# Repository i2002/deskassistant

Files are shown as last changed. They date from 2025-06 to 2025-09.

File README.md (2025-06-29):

# Deskassistant

## Introduction
Deskassistant is a compact device designed to help you increase your productivity. Placed on your desk, it keeps track of your priorities for the day and the time spent for each one. This project was presented as my graduation thesis for Computer Engineering Bachelor's Degree at Faculty of Mathematics and Computer Science, University of Bucharest.

## Repository structure
This repository contains the following:
- the software application written in QT
- PCB design for the connection board between Raspberry Pi Compute Module 5 and the rest of the peripherals (LCD display, touchscreen input, side buttons, brightness control, USB 2.0 interface)
- 3D design for the case backplate
- information about the OS-level configuration

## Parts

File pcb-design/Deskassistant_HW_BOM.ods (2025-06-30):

Reference | Description | Qty | Value | DNP | MPN | Manufacturer | SPN (Digikey) | URL | Exclude from BOM | Exclude from Board | Footprint | Footprint source | Datasheet
C1,C4,C26,C31,C37,C39,C45 | Generic capacitors | 7 | 10uF |  | GPC0805106 | - |  |  |  |  | Capacitor_SMD:C_0805_2012Metric |  | ~
C2 | Generic capacitors | 1 | 22uF |  | GPC0805226 | - |  |  |  |  | Capacitor_SMD:C_0805_2012Metric |  | ~
C3,C38 | Generic capacitors | 2 | 1uF |  | GPC0805105-25 | - |  |  |  |  | Capacitor_SMD:C_0805_2012Metric |  | ~
C5 | 470µF 25V Aluminum Electrolytic Capacitors Radial, Can - SMD 5000 Hrs @ 105°C | 1 | 470uF |  | 865060457009 | Wurth Elektronik | 732-8538-1-ND |  |  |  | Deskassistant_HW:CAPAE1030X1050L350X90N |  | ~
C6 | Generic capacitors | 1 | 2.7nF |  | GPC0805222 | - |  |  |  |  | Capacitor_SMD:C_0805_2012Metric |  | ~
C7 | Generic capacitors | 1 | 8.2nF |  | GPC0805682 | - |  |  |  |  | Capacitor_SMD:C_0805_2012Metric |  | ~
C8,C12,C18,C23 | Generic capacitors | 4 | 10uF |  | GPC1210106-25 | - |  |  |  |  | Capacitor_SMD:C_1210_3225Metric |  | ~
C9,C10,C11,C13,C14,C15,C16,C17,C19,C20,C21,C22,C24,C25,C46 | Generic capacitors | 15 | 0.1uF |  | GPC0805104 | - |  |  |  |  | Capacitor_SMD:C_0805_2012Metric |  | ~
C27,C30,C35 | Generic capacitors | 3 | 4.7uF |  | GPC0805475-16 | - |  |  |  |  | Capacitor_SMD:C_0805_2012Metric |  | ~
C28,C32,C34 | Generic capacitors | 3 | 220nF |  | GPC0805224 | - |  |  |  |  | Capacitor_SMD:C_0805_2012Metric |  | ~
C29,C40,C41,C42,C43,C44 | Generic capacitors | 5 | 100nF |  | GPC0805104 | - |  |  |  |  | Capacitor_SMD:C_0805_2012Metric |  | ~
C33 | Generic capacitors | 1 | 220nF |  | GPC0805224 | - |  |  |  |  | Capacitor_SMD:C_0805_2012Metric |  | ~
C36 | CAP CER 36PF 50V C0G/NP0 0805 | 1 | 36pF |  | C0805C360J5GACTU | Kemet | 399-C0805C360J5GACTUCT-ND |  |  |  | Capacitor_SMD:C_0805_2012Metric |  | ~
C47 | Tantalum Capacitors - Solid SMD 10V 150uF 10% | 1 | 150uF |  | TPSD157K010S0100 | AVX | 478-TPSD157K010S0100TR-ND |  |  |  | Capacitor_SMD:C_1210_3225Metric |  | ~
D1 | TVS DIODE 5VWM 9.2VC DO214AC | 1 | 5V |  | SMAJ5.0CA | Littlefuse | SMAJ5.0CALFCT-ND |  |  |  | Deskassistant_HW:DIONM510X266X229L115X145N |  | https://assets.nexperia.com/documents/data-sheet/PTVS10VZ1USK.pdf (https://www.murata.com/products/productdata/8796738650142/ENFA0003.pdf)
D2,D3,D4,D6,D7 | Diode Schottky 40V 1A Surface Mount SMA (DO-214AC) | 5 | SS14 |  | SS14 | ON Semiconductor | SS14DKR-ND |  |  |  | Diode_SMD:D_SMA |  | ~
D5 | Zener Diode 5.6 V 500 mW ±2% Surface Mount SOD-123 | 1 | 5.6V |  | MMSZ5232C-E3-08 | Vishay | MMSZ5232C-E3-08GICT-ND | https://www.digikey.com/en/products/detail/vishay-general-semiconductor-diodes-division/MMSZ5232C-E3-08/4832382 |  |  | Diode_SMD:D_SOD-123 |  | https://www.vishay.com/docs/86344/mmsz5225_to_mmsz5267.pdf
D8 | Zener Diode 9.1 V 500 mW ±2% Surface Mount SOD-123 | 1 | 9.1V |  | MMSZ5239C-E3-08 | Vishay | MMSZ5239C-E3-08GICT-ND | https://www.digikey.com/en/products/detail/vishay-general-semiconductor-diodes-division/MMSZ5239C-E3-08/4832424 |  |  | Diode_SMD:D_SOD-123 |  | https://www.vishay.com/docs/86344/mmsz5225_to_mmsz5267.pdf
FB1,FB2,FB3,FB4 | Ferrite Beads Multi-Layer 600Ohm 25% 100MHz 200mA 600mOhm DCR 0603 Paper T/R | 4 |  |  | BLM18RK601SN1D | Murata | 490-5227-1-ND | https://www.digikey.com/en/products/detail/murata-electronics/BLM18RK601SN1D/1948332 |  |  | Inductor_SMD:L_0603_1608Metric |  | https://www.murata.com/products/productdata/8796738650142/ENFA0003.pdf
J1 | USB-C (USB TYPE-C) USB 2.0 Receptacle Connector 24 (16+8 Dummy) Position | 1 |  |  | USB4145-03-0170-C | GCT | 2073-USB4145-03-0170-CCT-ND | https://www.digikey.com/en/products/detail/gct/USB4145-03-0170-C/16649098 |  |  | Deskassistant_HW:CONN_GCT_USB4145-03-0170-C |  | https://gct.co/files/specs/usb4145-spec.pdf
J2 | 6 Position FFC, FPC Connector Contacts, Bottom 0.020" (0.50mm) Surface Mount, Right Angle | 1 | Conn_01x06_Socket |  | 0527460671 | Molex | WM7977CT-ND | https://www.digikey.com/en/products/detail/molex/0527460671/2074148?s=N4IgTCBcDaIAwFYwHYAsA2O7kEYQF0BfIA |  |  | Deskassistant_HW:MOLEX_0527460671 |  | ~
J3 | 50 Position FPC Connector Contacts, Top 0.020" (0.50mm) Surface Mount, Right Angle | 1 | 62684-502100ALF |  | 62684-502100ALF | Amphenol | 609-1202-1-ND | https://www.digikey.com/en/products/detail/amphenol-cs-fci/62684-502100ALF/1001516 |  |  | Deskassistant_HW:CONN50_62684-502100ALF_FCI |  | https://www.waldom.com/upload/parts/datasheets/mf-fci/fci-62684-502100alf.pdf
J4 | USB-A (USB TYPE-A) USB 2.0 Receptacle Connector 4 Position Through Hole | 1 | USB_A |  | UE27AE54100 | Amphenol | UE27AE54100-ND | https://www.digikey.com/en/products/detail/amphenol-cs-commercial-products/UE27AE54100/1972254 |  |  | Deskassistant_HW:AMPHENOL_UE27AE54100 |  | ~
J5,J6 | 100 Position Connector Receptacle, Center Strip Contacts Surface Mount Gold | 2 | ComputeModule5 |  | 10164227-1001A1RLF | Amphenol | 609-10164227-1001A1RLFCT-ND | https://www.digikey.com/en/products/detail/amphenol-cs-fci/10164227-1001A1RLF/16908921 |  |  | Deskassistant_HW:CONN_AMPHENOL_10164227-1001A1RLF
L1 | 2.2 µH Shielded Drum Core, Wirewound Inductor 1.5 A 72mOhm Max Nonstandard | 1 | 2.2uH |  | NR3015T2R2M | Taiyo Yuden | 587-1648-1-ND | https://www.digikey.com/en/products/detail/taiyo-yuden/NR3015T2R2M/958029 |  |  | Deskassistant_HW:L_NR3015T2R2M |  | https://mm.digikey.com/Volume0/opasdata/d220001/medias/docus/610/NR3015T2R2M_SS.pdf
L2,L3 | 10 µH Shielded Drum Core, Wirewound Inductor 1.13 A 237mOhm Max Nonstandard | 2 | 10uH |  | VLCF5020T-100M1R1-1 | TDK | 445-3209-1-ND | https://www.digikey.com/en/products/detail/tdk-corporation/VLCF5020T-100M1R1-1/1132635 |  |  | Inductor_SMD:L_Sumida_CR75 |  | https://product.tdk.com/en/system/files
Q1 | Bipolar (BJT) Transistor NPN 40 V 600 mA 300MHz 300 mW Surface Mount SOT-23-3 | 1 | 1AM |  | BC847A,215 | Nexperia | 1727-4240-1-ND | https://www.digikey.com/en/products/detail/nexperia-usa-inc/BC847A-215/1232273 |  |  | Package_TO_SOT_SMD:SOT-23 |  | https://www.onsemi.com/pdf/datasheet/pzt3904-d.pdf (https://www.murata.com/products/productdata/8796738650142/ENFA0003.pdf)
R1 | Generic resistor | 1 | 2.2k |  | GPR08052K2 | - |  |  |  |  | Resistor_SMD:R_0805_2012Metric |  | ~
R2,R3,R4,R5,R6,R12,R13,R16,R17,R18,R19,R20,R31,R32,R33 | Generic resistor | 15 | 10k |  | GPR080510K | - |  |  |  |  | Resistor_SMD:R_0805_2012Metric |  | ~
R7 | Generic resistor | 1 | 470k |  | GPR0805470K | - |  |  |  |  | Resistor_SMD:R_0805_2012Metric |  | ~
R8 | Generic resistor | 1 | 178k |  | GPR0805180K | - |  |  |  |  | Resistor_SMD:R_0805_2012Metric |  | ~
R9 | Generic resistor | 1 | 681 |  | GPR0805680R | - |  |  |  |  | Resistor_SMD:R_0805_2012Metric |  | ~
R10 | Generic resistor | 1 | 47k |  | GPR080547K | - |  |  |  |  | Resistor_SMD:R_0805_2012Metric |  | ~
R11 | Generic resistor | 1 | 17.4k |  | GPR080518K | - |  |  |  |  | Resistor_SMD:R_0805_2012Metric |  | ~
R14,R15,R21,R22,R23,R26 | Generic resistor | 6 | 0 | DNP | GPR080510K |  |  |  |  |  | Resistor_SMD:R_0805_2012Metric |  | ~
R24 | Generic resistor | 1 | 22 |  | GPR080522R | - |  |  |  |  | Resistor_SMD:R_0805_2012Metric |  | ~
R25 | Generic resistor | 1 | 1k |  | GPR08051K | - |  |  |  |  | Resistor_SMD:R_0805_2012Metric |  | ~
R27 | Generic resistor | 1 | 1.27 |  | GPR08051R2 | - |  |  |  |  | Resistor_SMD:R_0805_2012Metric |  | ~
R28 | Generic resistor | 1 | 15k |  | GPR080515K | - |  |  |  |  | Resistor_SMD:R_0805_2012Metric |  | ~
R29 | Generic resistor | 1 | 6.8k |  | GPR08056K8 | - |  |  |  |  | Resistor_SMD:R_0805_2012Metric |  | ~
R30 | Generic resistor | 1 | 120k |  | GPR0805120K | - |  |  |  |  | Resistor_SMD:R_0805_2012Metric |  | ~
RN1,RN2,RN3,RN4,RN5,RN6,RN7 | 33 Ohm ±1% 31mW Power Per Element Isolated 4 Resistor Network/Array ±200ppm/°C 0502 (1406 Metric) Convex, Long Side Terminals | 7 | 33 |  | CAY16-33R0F4LF | Bourns | CAY16-33R0F4LFCT-ND | https://www.digikey.ro/en/products/detail/bourns-inc/CAY16-33R0F4LF/2566572 |  |  | Resistor_SMD:R_Array_Convex_4x0603 |  | https://www.bourns.com/docs/Product-Datasheets/CATCAY.pdf
RV1 |  | 1 | ~ |  | TS53YL103MR10 | Vishay Sfernice | TS53YL-10KCT-ND | https://www.digikey.com/en/products/detail/vishay-sfernice/TS53YL103MR10/1587849 |  |  | Potentiometer_SMD:Potentiometer_Bourns_3214J_Horizontal |  | https://www.vishay.com/docs/51008/ts53.pdf
SW1,SW2,SW3,SW4,SW5 | Tactile Switch SPST-NO Side Actuated Surface Mount, Right Angle | 5 | SW_Push |  | TL3330AF260QG | E-Switch | EG4389CT-ND | https://www.digikey.com/en/products/detail/e-switch/TL3330AF260QG/1426836 |  |  | Deskassistant_HW:SW_ESWITCH_TL3330AF260QG |  | ~
U1 | Buck Switching Regulator IC Positive Fixed 3.3V 1 Output 1A 8-WFDFN Exposed Pad | 1 |  |  | TPS62162DSGR | Texas Instruments | 296-43671-1-ND | https://www.digikey.com/en/products/detail/texas-instruments/TPS62162DSGR/2833447 |  |  | Package_SON:WSON-8-1EP_2x2mm_P0.5mm_EP0.9x1.6mm_ThermalVias | https://www.digikey.com/en/products/detail/texas-instruments/TPS62162DSGR/2833447 | http://www.ti.com/lit/ds/symlink/tps62160.pdf (https://www.murata.com/products/productdata/8796738650142/ENFA0003.pdf)
U2 | Electronic Fuse Regulator 5.5A 10-VQFN-HR (2x2) | 1 |  |  | TPS259472ARPWR | Texas Instruments | 296-TPS259472ARPWRCT-ND | https://www.digikey.com/en/products/detail/texas-instruments/TPS259472ARPWR/14124020 |  |  | Deskassistant_HW:RPW0010A-MFG |  | https://www.ti.com/general/docs/suppproductinfo.tsp?distId=10
U3 | 0/3 Receiver PanelBus™ 100-HTQFP (14x14) | 1 |  |  | TFP401APZPR | Texas Instruments | 296-53174-1-ND | https://www.digikey.com/en/products/detail/texas-instruments/TFP401APZPR/9861440 |  |  | Deskassistant_HW:PZP100_5P2X5P2 |  | https://www.ti.com/general/docs/suppproductinfo.tsp?distId=10
U4 | LED Driver IC 1 Output DC DC Regulator Step-Up (Boost) PWM Dimming 1.2A (Switch) SOT-23-6 | 1 |  |  | TPS61165DBVR | Texas Instruments | 296-27597-1-ND | https://www.digikey.com/en/products/detail/texas-instruments/TPS61165DBVR/2340764 |  |  | Package_TO_SOT_SMD:SOT-23-6 |  | https://www.ti.com/lit/ds/symlink/tps61165.pdf (https://www.murata.com/products/productdata/8796738650142/ENFA0003.pdf)
U5 | LED Driver IC 1 Output DC DC Regulator Step-Up (Boost) PWM Dimming 350mA (Switch) SOT-23-5 | 1 |  |  | TPS61040DBVR | Texas Instruments | 296-12685-1-ND | https://www.digikey.com/en/products/detail/texas-instruments/TPS61040DBVR/454263 |  |  | Package_TO_SOT_SMD:SOT-23-5 |  | http://www.ti.com/lit/ds/symlink/tps61040.pdf (https://www.murata.com/products/productdata/8796738650142/ENFA0003.pdf)
U6 | IC PWR SWITCH N-CHAN 1:1 SOT23-5 | 1 |  |  | TPS2041CDBVT | Texas Instruments | 296-35520-1-ND | https://www.digikey.com/en/products/detail/texas-instruments/TPS2041CDBVT/3778698 |  |  | Package_TO_SOT_SMD:SOT-23-5 |  | https://www.ti.com/lit/ds/symlink/tps2041c.pdf (https://www.murata.com/products/productdata/8796738650142/ENFA0003.pdf)

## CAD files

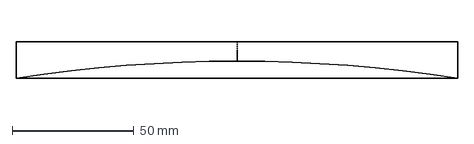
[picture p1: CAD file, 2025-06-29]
case-design/sketch_ecran_sides.dxf
181.0 x 15.0 mm

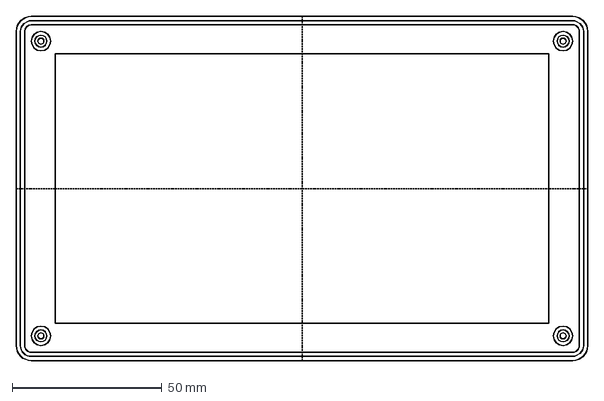
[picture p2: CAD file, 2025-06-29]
case-design/sketch_backplate_base.dxf
191.0 x 115.0 mm

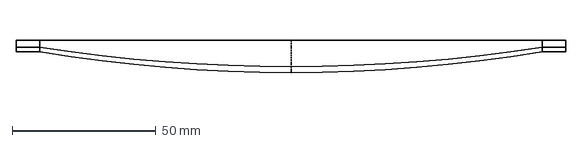
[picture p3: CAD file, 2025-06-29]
case-design/sketch_backplate_side.dxf
191.0 x 13.6 mm

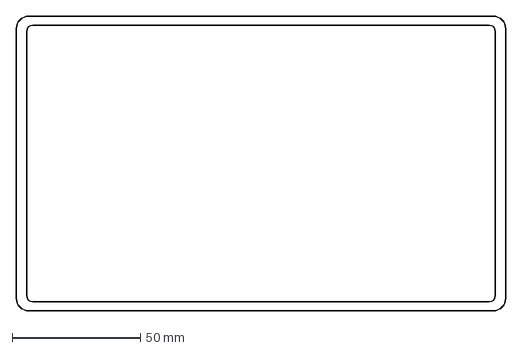
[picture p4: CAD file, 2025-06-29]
case-design/sketch_ecran_base.dxf
191.0 x 115.0 mm

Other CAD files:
case-design/Case - v1 v3.f3d

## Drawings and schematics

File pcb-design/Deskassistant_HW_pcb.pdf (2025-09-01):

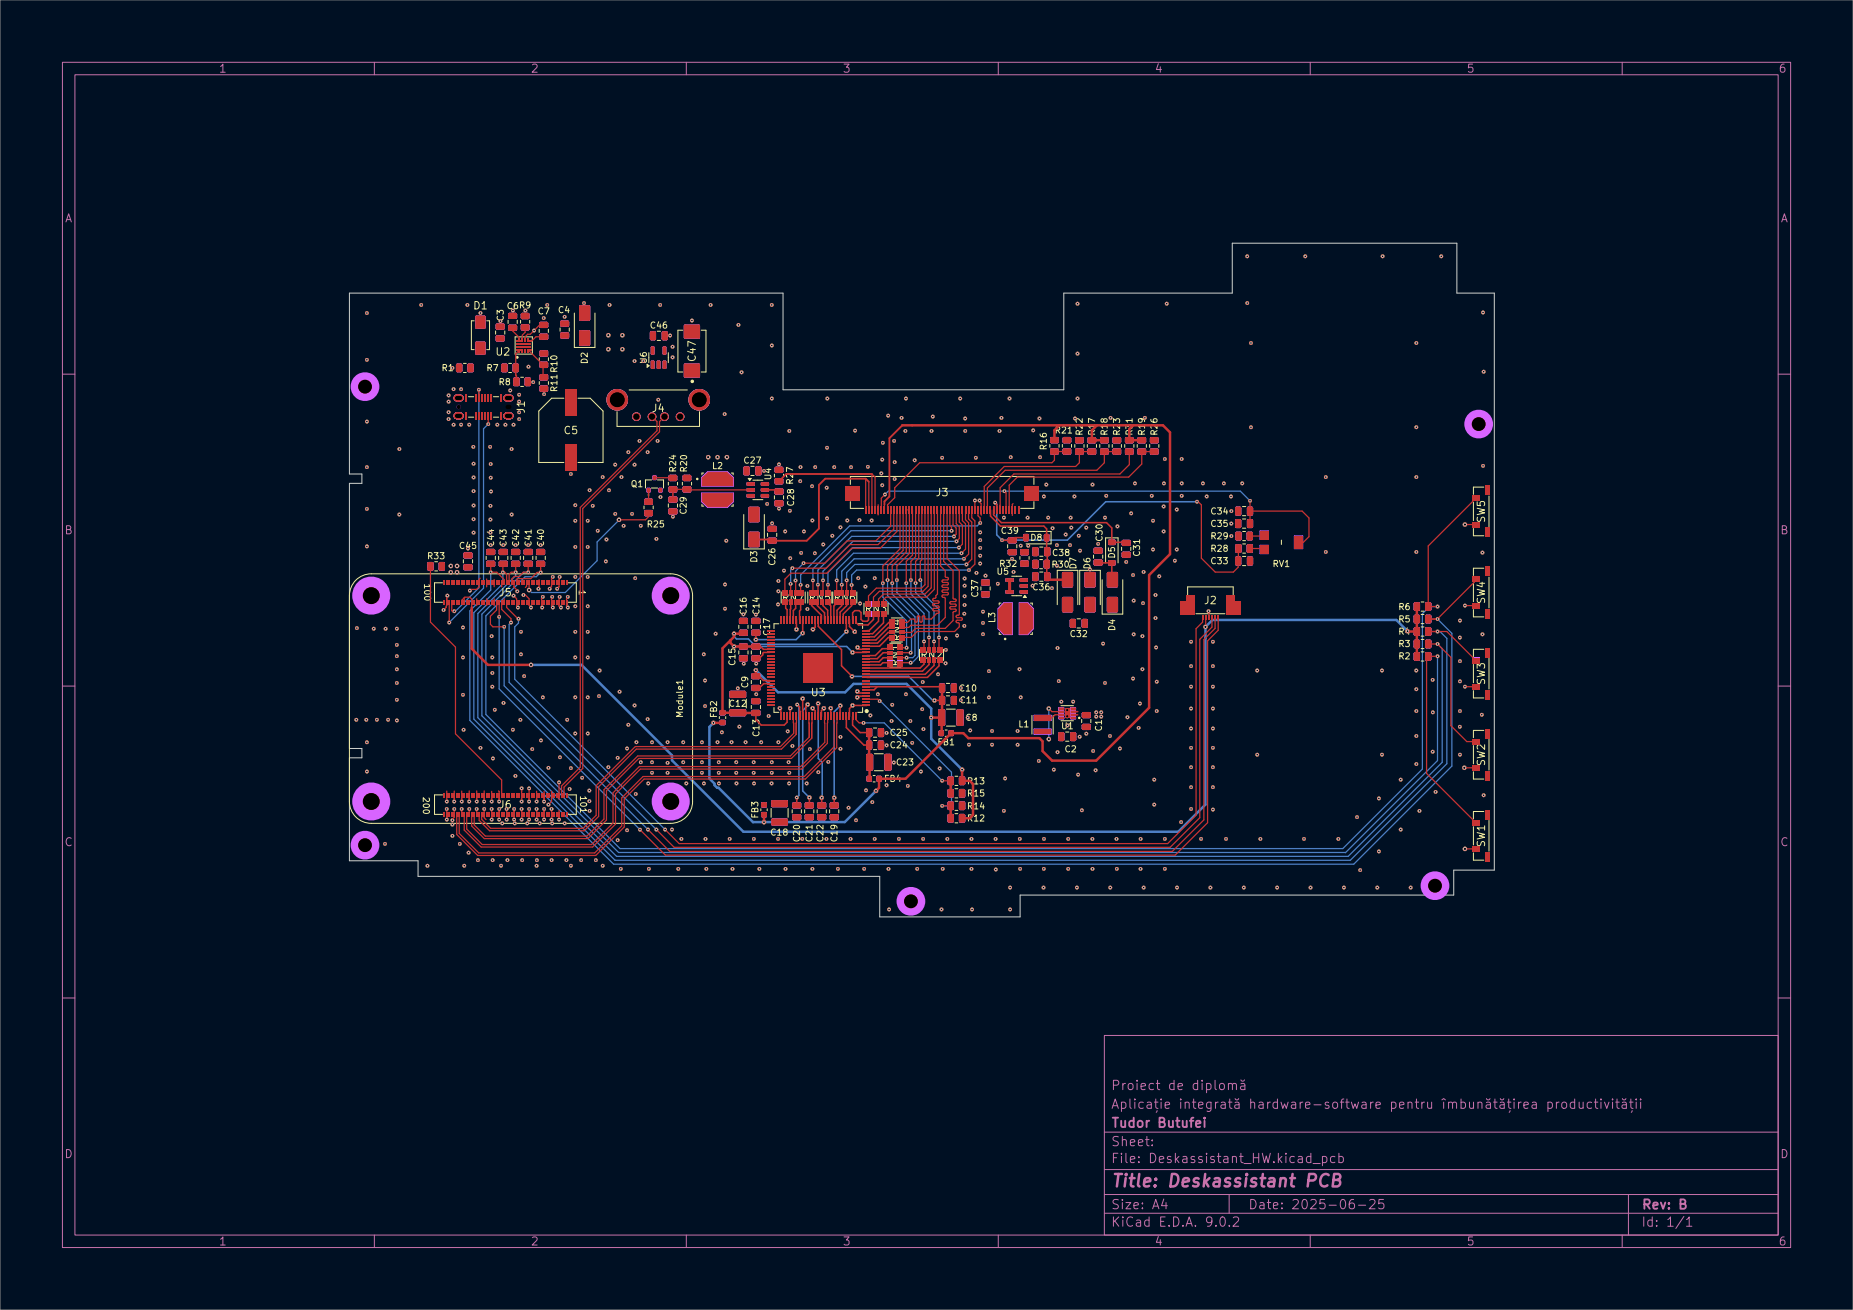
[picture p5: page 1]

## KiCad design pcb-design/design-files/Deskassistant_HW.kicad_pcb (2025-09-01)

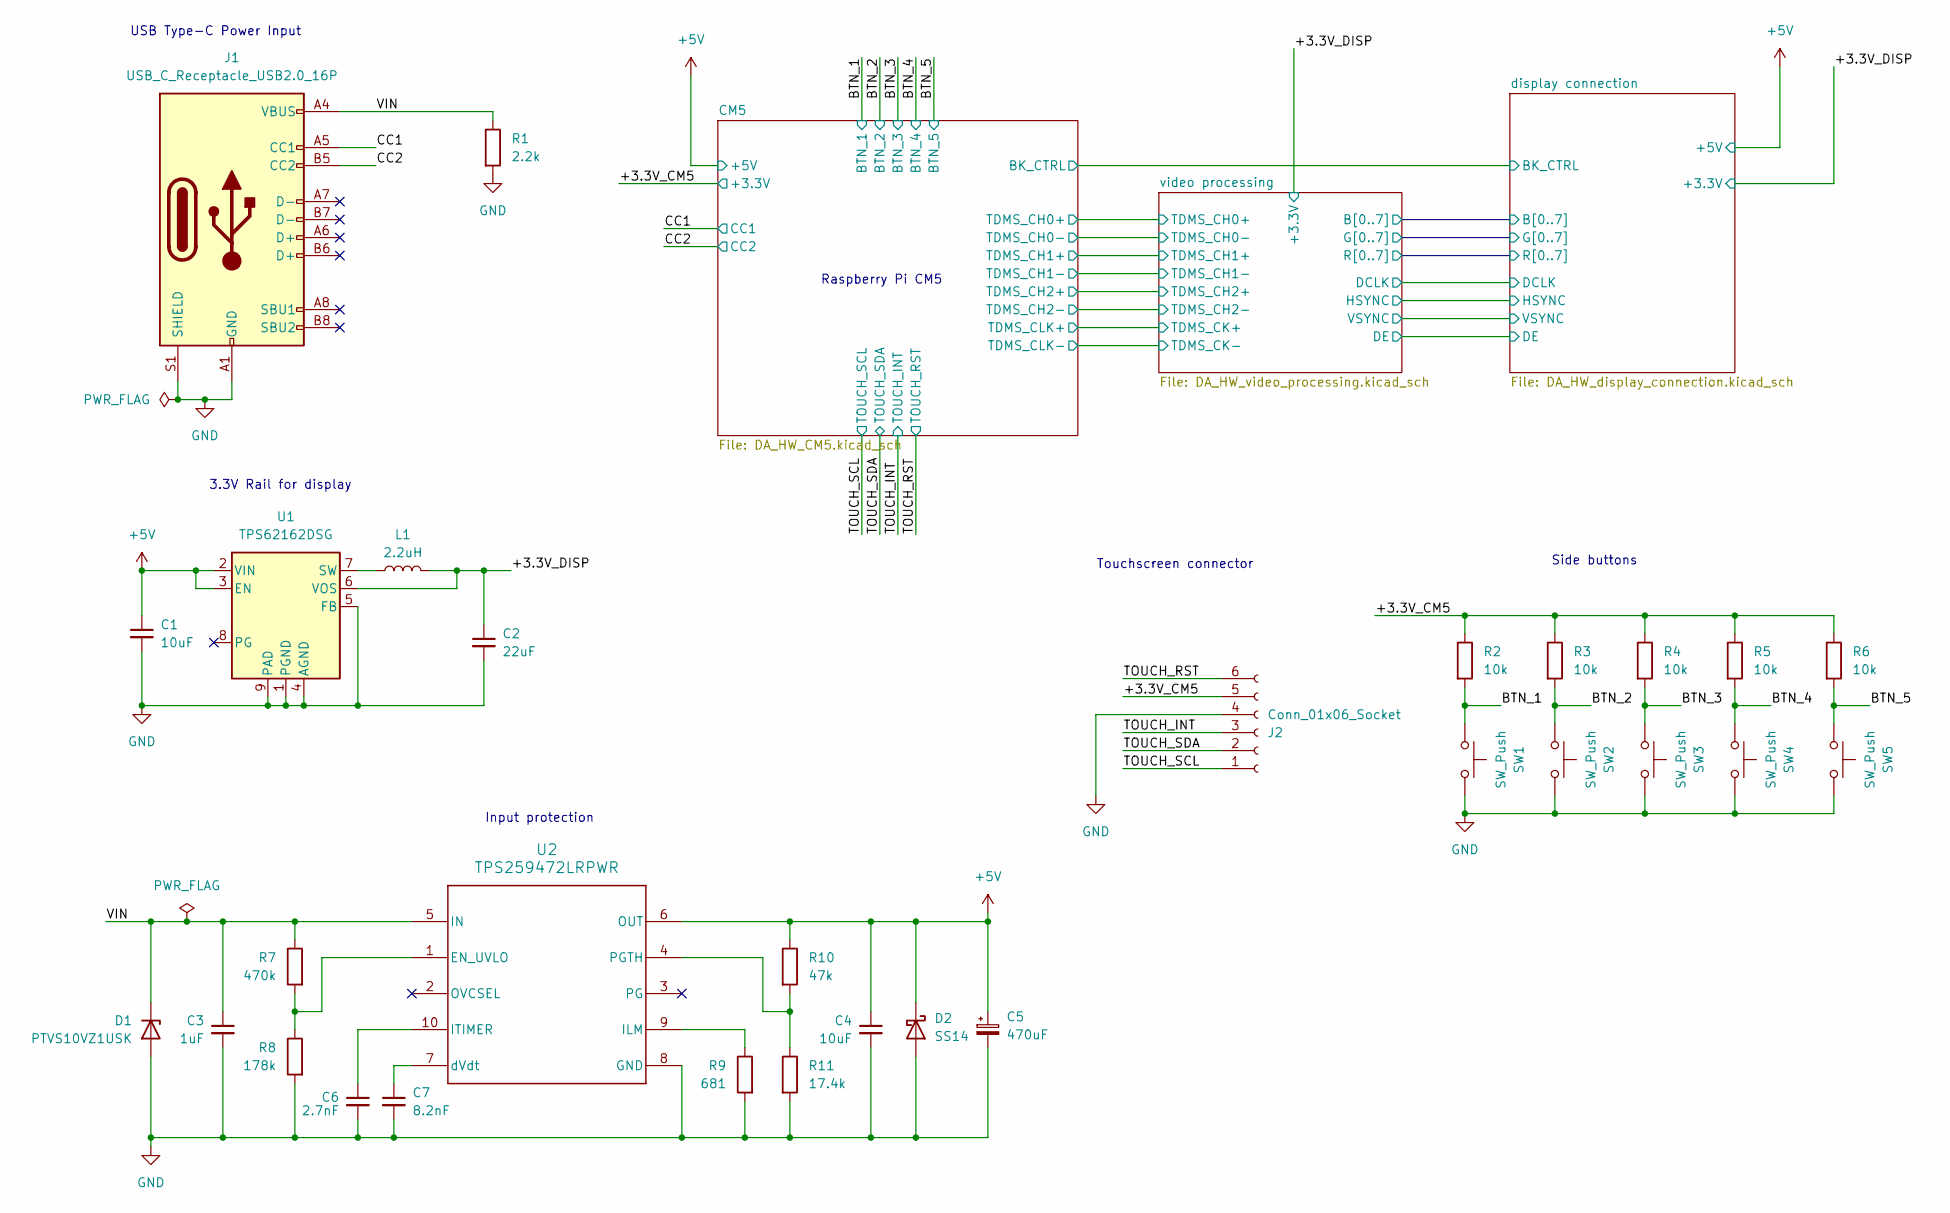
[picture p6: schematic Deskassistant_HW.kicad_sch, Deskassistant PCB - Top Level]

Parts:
C1, C4: 10uF; C_0805_2012Metric
C2: 22uF; C_0805_2012Metric
C3: 1uF; C_0805_2012Metric
C5: 470uF; CAPAE1030X1050L350X90N
C6: 2.7nF; C_0805_2012Metric
C7: 8.2nF; C_0805_2012Metric
D1: PTVS10VZ1USK; DIONM510X266X229L115X145N
D2: SS14; D_SMA
J1: USB_C_Receptacle_USB2.0_16P; CONN_GCT_USB4145-03-0170-C
J2: Conn_01x06_Socket; MOLEX_0527460671
L1: 2.2uH; L_NR3015T2R2M
R1: 2.2k; R_0805_2012Metric
R2, R3, R4, R5, R6: 10k; R_0805_2012Metric
R7: 470k; R_0805_2012Metric
R8: 178k; R_0805_2012Metric
R9: 681; R_0805_2012Metric
R10: 47k; R_0805_2012Metric
R11: 17.4k; R_0805_2012Metric
SW1, SW2, SW3, SW4, SW5: SW_Push; SW_ESWITCH_TL3330AF260QG
U1: TPS62162DSG; SON50P200X200X80-9N
U2: TPS259472LRPWR; ICS_TI_TPS259472ARPWR

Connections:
+5V: C1.1, C4.1, C5.1, D2.1 (K), R10.1, U1.2 (VIN), U1.3 (EN), U2.6 (OUT); also elsewhere on the board
/+3.3V_CM5: J2.5, R2.1, R3.1, R4.1, R5.1, R6.1; also elsewhere on the board
/+3.3V_DISP: C2.1, L1.2, U1.6 (VOS); also elsewhere on the board
/BTN_1: R2.2, SW1.1; also elsewhere on the board
/BTN_2: R3.2, SW2.1; also elsewhere on the board
/BTN_3: R4.2, SW3.1; also elsewhere on the board
/BTN_4: R5.2, SW4.1; also elsewhere on the board
/BTN_5: R6.2, SW5.1; also elsewhere on the board
/CC1: J1.A5 (CC1); also elsewhere on the board
/CC2: J1.B5 (CC2); also elsewhere on the board
/TOUCH_INT: J2.3; also elsewhere on the board
/TOUCH_RST: J2.6; also elsewhere on the board
/TOUCH_SCL: J2.1; also elsewhere on the board
/TOUCH_SDA: J2.2; also elsewhere on the board
/VIN: C3.1, D1.1 (K), J1.A4 (VBUS), J1.A9 (VBUS), J1.B4 (VBUS), J1.B9 (VBUS), R1.1, R7.1, U2.5 (IN)
GND: C1.2, C2.2, C3.2, C4.2, C5.2, C6.2, C7.2, D1.2 (A), D2.2 (A), J1.A1 (GND), J1.A12 (GND), J1.B1 (GND), J1.B12 (GND), J1.S1 (SHIELD), J2.4, J2.7, R1.2, R8.2, R9.2, R11.2, SW1.2, SW2.2, SW3.2, SW4.2, SW5.2, U1.1 (PGND), U1.4 (AGND), U1.5 (FB), U1.9 (PAD), U1.10, U1.11, U2.8 (GND); also elsewhere on the board
unnamed: L1.1, U1.7 (SW)
unnamed: R7.2, R8.1, U2.1 (EN_UVLO)
unnamed: R9.1, U2.9 (ILM)
unnamed: C6.1, U2.10 (ITIMER)
unnamed: R10.2, R11.1, U2.4 (PGTH)
unnamed: C7.1, U2.7 (dVdt)

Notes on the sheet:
3.3V Rail for display
USB Type-C Power Input
Input protection
Touchscreen connector
Side buttons
Raspberry Pi CM5

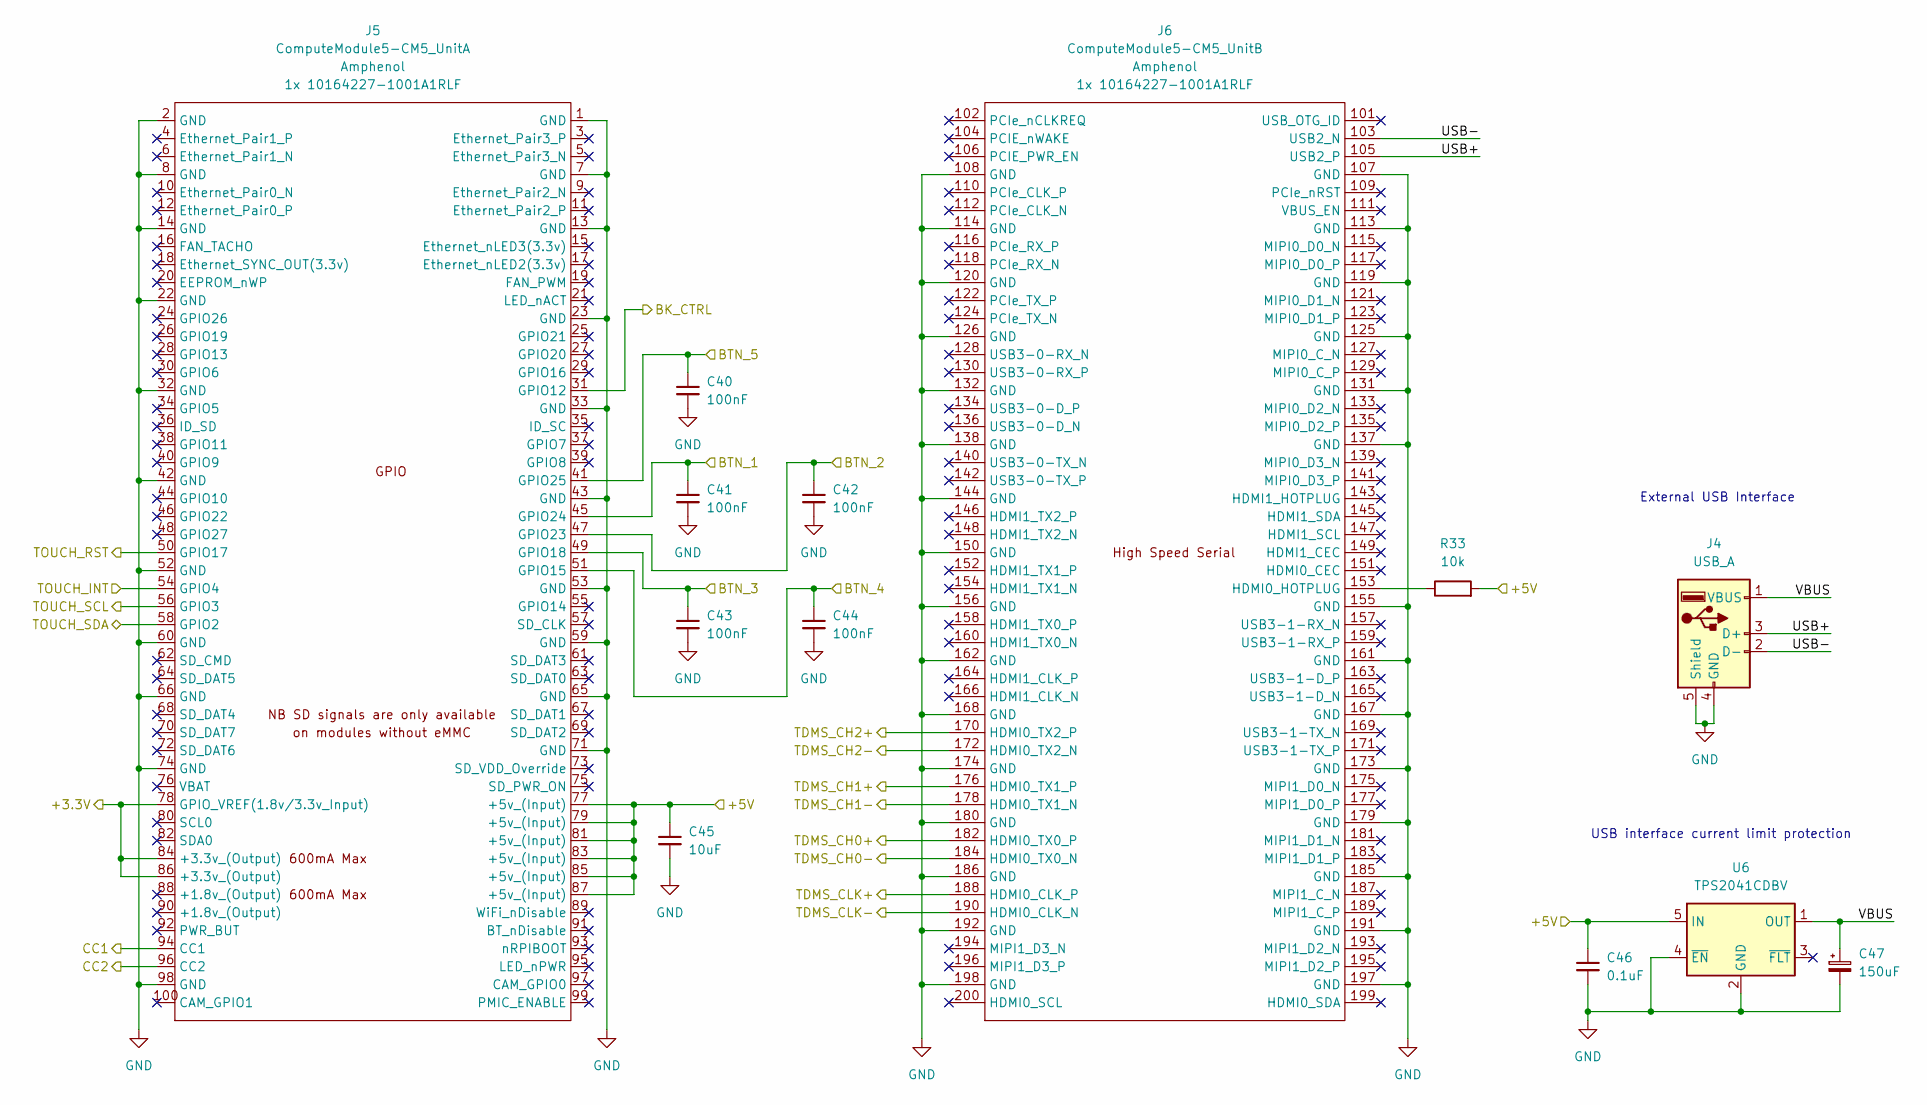
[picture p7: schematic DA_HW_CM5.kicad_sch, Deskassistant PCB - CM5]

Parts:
C40, C41, C42, C43, C44: 100nF; C_0805_2012Metric
C45: 10uF; C_0805_2012Metric
C46: 0.1uF; C_0805_2012Metric
C47: 150uF; CAPPM730X435X310L135X240NN
J4: USB_A; AMPHENOL_UE27AE54100
J5: ComputeModule5-CM5_UnitA; CONN_AMPHENOL_10164227-1001A1RLF_UnitA
J6: ComputeModule5-CM5_UnitB; CONN_AMPHENOL_10164227-1001A1RLF_UnitB
R33: 10k; R_0805_2012Metric
U6: TPS2041CDBV; SOT-23-5

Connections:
+5V: C45.1, C46.1, J5.77 (+5v_(Input)), J5.79 (+5v_(Input)), J5.81 (+5v_(Input)), J5.83 (+5v_(Input)), J5.85 (+5v_(Input)), J5.87 (+5v_(Input)), R33.2, U6.5 (IN); also elsewhere on the board
/+3.3V_CM5: J5.78 (GPIO_VREF(1.8v/3.3v_Input)), J5.84 (+3.3v_(Output)), J5.86 (+3.3v_(Output)); also elsewhere on the board
/BTN_1: C41.1, J5.45 (GPIO24); also elsewhere on the board
/BTN_2: C42.1, J5.47 (GPIO23); also elsewhere on the board
/BTN_3: C43.1, J5.49 (GPIO18); also elsewhere on the board
/BTN_4: C44.1, J5.51 (GPIO15); also elsewhere on the board
/BTN_5: C40.1, J5.41 (GPIO25); also elsewhere on the board
/CC1: J5.94 (CC1); also elsewhere on the board
/CC2: J5.96 (CC2); also elsewhere on the board
/CM5/BK_CTRL: J5.31 (GPIO12); also elsewhere on the board
/CM5/TDMS_CH0+: J6.182 (HDMI0_TX0_P); also elsewhere on the board
/CM5/TDMS_CH0-: J6.184 (HDMI0_TX0_N); also elsewhere on the board
/CM5/TDMS_CH1+: J6.176 (HDMI0_TX1_P); also elsewhere on the board
/CM5/TDMS_CH1-: J6.178 (HDMI0_TX1_N); also elsewhere on the board
/CM5/TDMS_CH2+: J6.170 (HDMI0_TX2_P); also elsewhere on the board
/CM5/TDMS_CH2-: J6.172 (HDMI0_TX2_N); also elsewhere on the board
/CM5/TDMS_CLK+: J6.188 (HDMI0_CLK_P); also elsewhere on the board
/CM5/TDMS_CLK-: J6.190 (HDMI0_CLK_N); also elsewhere on the board
/CM5/USB+: J4.3 (D+), J6.105 (USB2_P)
/CM5/USB-: J4.2 (D-), J6.103 (USB2_N)
/CM5/VBUS: C47.1, J4.1 (VBUS), U6.1 (OUT)
/TOUCH_INT: J5.54 (GPIO4); also elsewhere on the board
/TOUCH_RST: J5.50 (GPIO17); also elsewhere on the board
/TOUCH_SCL: J5.56 (GPIO3); also elsewhere on the board
/TOUCH_SDA: J5.58 (GPIO2); also elsewhere on the board
GND: C40.2, C41.2, C42.2, C43.2, C44.2, C45.2, C46.2, C47.2, J4.4 (GND), J4.5 (Shield), J5.1 (GND), J5.2 (GND), J5.7 (GND), J5.8 (GND), J5.13 (GND), J5.14 (GND), J5.22 (GND), J5.23 (GND), J5.32 (GND), J5.33 (GND), J5.42 (GND), J5.43 (GND), J5.52 (GND), J5.53 (GND), J5.59 (GND), J5.60 (GND), J5.65 (GND), J5.66 (GND), J5.71 (GND), J5.74 (GND), J5.98 (GND), J6.107 (GND), J6.108 (GND), J6.113 (GND), J6.114 (GND), J6.119 (GND), J6.120 (GND), J6.125 (GND), J6.126 (GND), J6.131 (GND), J6.132 (GND), J6.137 (GND), J6.138 (GND), J6.144 (GND), J6.150 (GND), J6.155 (GND), J6.156 (GND), J6.161 (GND), J6.162 (GND), J6.167 (GND), J6.168 (GND), J6.173 (GND), J6.174 (GND), J6.179 (GND), J6.180 (GND), J6.185 (GND), J6.186 (GND), J6.191 (GND), J6.192 (GND), J6.197 (GND), J6.198 (GND), U6.2 (GND), U6.4 (~EN); also elsewhere on the board
unnamed: J6.153 (HDMI0_HOTPLUG), R33.1

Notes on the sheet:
USB interface current limit protection
External USB Interface

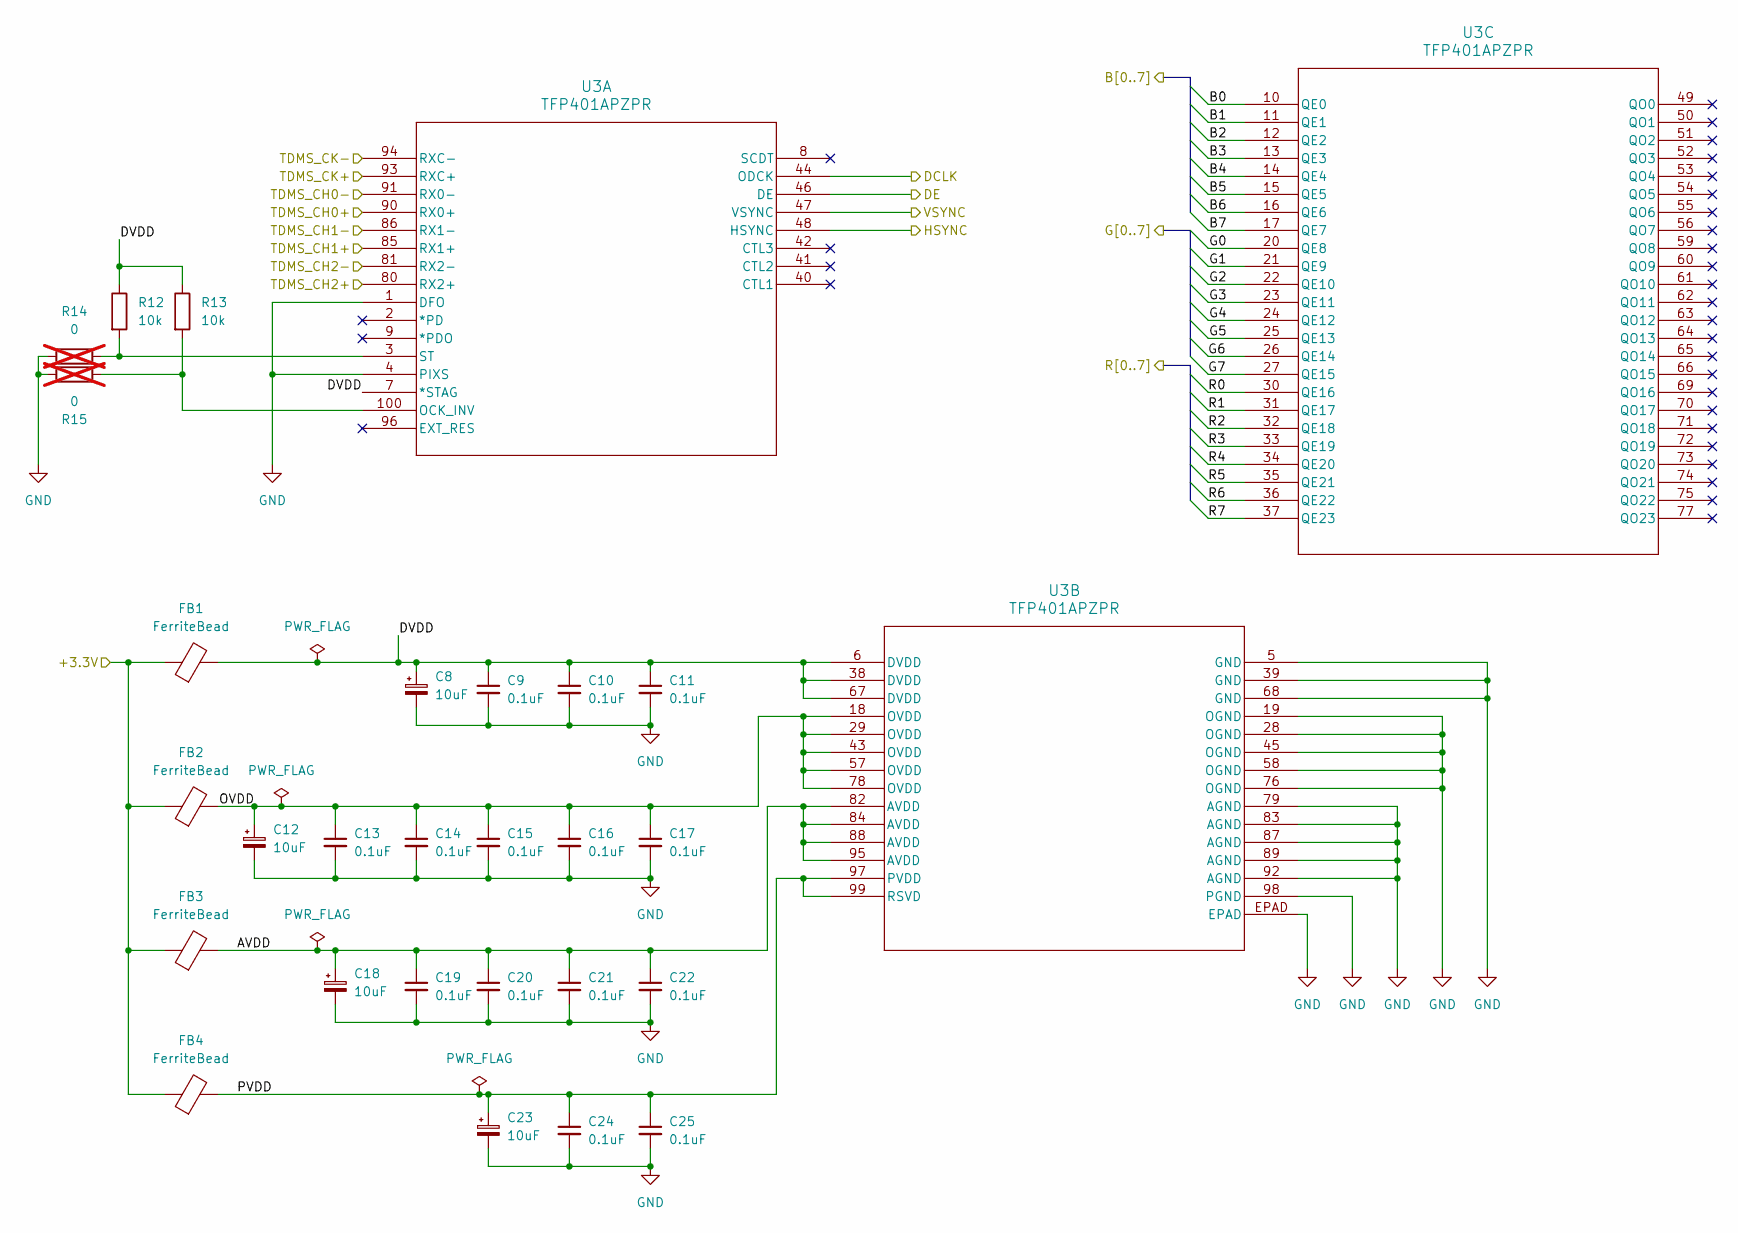
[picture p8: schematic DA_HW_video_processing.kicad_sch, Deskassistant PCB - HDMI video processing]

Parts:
C8, C12, C18, C23: 10uF; C_1210_3225Metric
C9, C10, C11, C13, C14, C15, C16, C17, C19, C20, C21, C22, C24, C25: 0.1uF; C_0805_2012Metric
FB1, FB2, FB3, FB4: FerriteBead; L_0603_1608Metric
R12, R13: 10k; R_0805_2012Metric
R14, R15: 0; R_0805_2012Metric; not fitted
U3: TFP401APZPR; PZP100_5P2X5P2

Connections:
/+3.3V_DISP: FB1.1, FB2.1, FB3.1, FB4.1; also elsewhere on the board
/CM5/TDMS_CH0+: U3.90 (RX0+); also elsewhere on the board
/CM5/TDMS_CH0-: U3.91 (RX0-); also elsewhere on the board
/CM5/TDMS_CH1+: U3.85 (RX1+); also elsewhere on the board
/CM5/TDMS_CH1-: U3.86 (RX1-); also elsewhere on the board
/CM5/TDMS_CH2+: U3.80 (RX2+); also elsewhere on the board
/CM5/TDMS_CH2-: U3.81 (RX2-); also elsewhere on the board
/CM5/TDMS_CLK+: U3.93 (RXC+); also elsewhere on the board
/CM5/TDMS_CLK-: U3.94 (RXC-); also elsewhere on the board
/display connection/B0: U3.10 (QE0); also elsewhere on the board
/display connection/B1: U3.11 (QE1); also elsewhere on the board
/display connection/B2: U3.12 (QE2); also elsewhere on the board
/display connection/B3: U3.13 (QE3); also elsewhere on the board
/display connection/B4: U3.14 (QE4); also elsewhere on the board
/display connection/B5: U3.15 (QE5); also elsewhere on the board
/display connection/B6: U3.16 (QE6); also elsewhere on the board
/display connection/B7: U3.17 (QE7); also elsewhere on the board
/display connection/DCLK: U3.44 (ODCK); also elsewhere on the board
/display connection/DE: U3.46 (DE); also elsewhere on the board
/display connection/G0: U3.20 (QE8); also elsewhere on the board
/display connection/G1: U3.21 (QE9); also elsewhere on the board
/display connection/G2: U3.22 (QE10); also elsewhere on the board
/display connection/G3: U3.23 (QE11); also elsewhere on the board
/display connection/G4: U3.24 (QE12); also elsewhere on the board
/display connection/G5: U3.25 (QE13); also elsewhere on the board
/display connection/G6: U3.26 (QE14); also elsewhere on the board
/display connection/G7: U3.27 (QE15); also elsewhere on the board
/display connection/HSYNC: U3.48 (HSYNC); also elsewhere on the board
/display connection/R0: U3.30 (QE16); also elsewhere on the board
/display connection/R1: U3.31 (QE17); also elsewhere on the board
/display connection/R2: U3.32 (QE18); also elsewhere on the board
/display connection/R3: U3.33 (QE19); also elsewhere on the board
/display connection/R4: U3.34 (QE20); also elsewhere on the board
/display connection/R5: U3.35 (QE21); also elsewhere on the board
/display connection/R6: U3.36 (QE22); also elsewhere on the board
/display connection/R7: U3.37 (QE23); also elsewhere on the board
/display connection/VSYNC: U3.47 (VSYNC); also elsewhere on the board
/video processing/AVDD: C18.1, C19.1, C20.1, C21.1, C22.1, FB3.2, U3.82 (AVDD), U3.84 (AVDD), U3.88 (AVDD), U3.95 (AVDD)
/video processing/DVDD: C8.1, C9.1, C10.1, C11.1, FB1.2, R12.1, R13.1, U3.6 (DVDD), U3.7 (*STAG), U3.38 (DVDD), U3.67 (DVDD)
/video processing/OVDD: C12.1, C13.1, C14.1, C15.1, C16.1, C17.1, FB2.2, U3.18 (OVDD), U3.29 (OVDD), U3.43 (OVDD), U3.57 (OVDD), U3.78 (OVDD)
/video processing/PVDD: C23.1, C24.1, C25.1, FB4.2, U3.97 (PVDD), U3.99 (RSVD)
GND: C8.2, C9.2, C10.2, C11.2, C12.2, C13.2, C14.2, C15.2, C16.2, C17.2, C18.2, C19.2, C20.2, C21.2, C22.2, C23.2, C24.2, C25.2, R14.1, R15.1, U3.1 (DFO), U3.4 (PIXS), U3.5 (GND), U3.19 (OGND), U3.28 (OGND), U3.39 (GND), U3.45 (OGND), U3.58 (OGND), U3.68 (GND), U3.76 (OGND), U3.79 (AGND), U3.83 (AGND), U3.87 (AGND), U3.89 (AGND), U3.92 (AGND), U3.98 (PGND), U3.101, U3.EPAD, U3.V (Pad); also elsewhere on the board
unnamed: R13.2, R15.2, U3.100 (OCK_INV)
unnamed: R12.2, R14.2, U3.3 (ST)

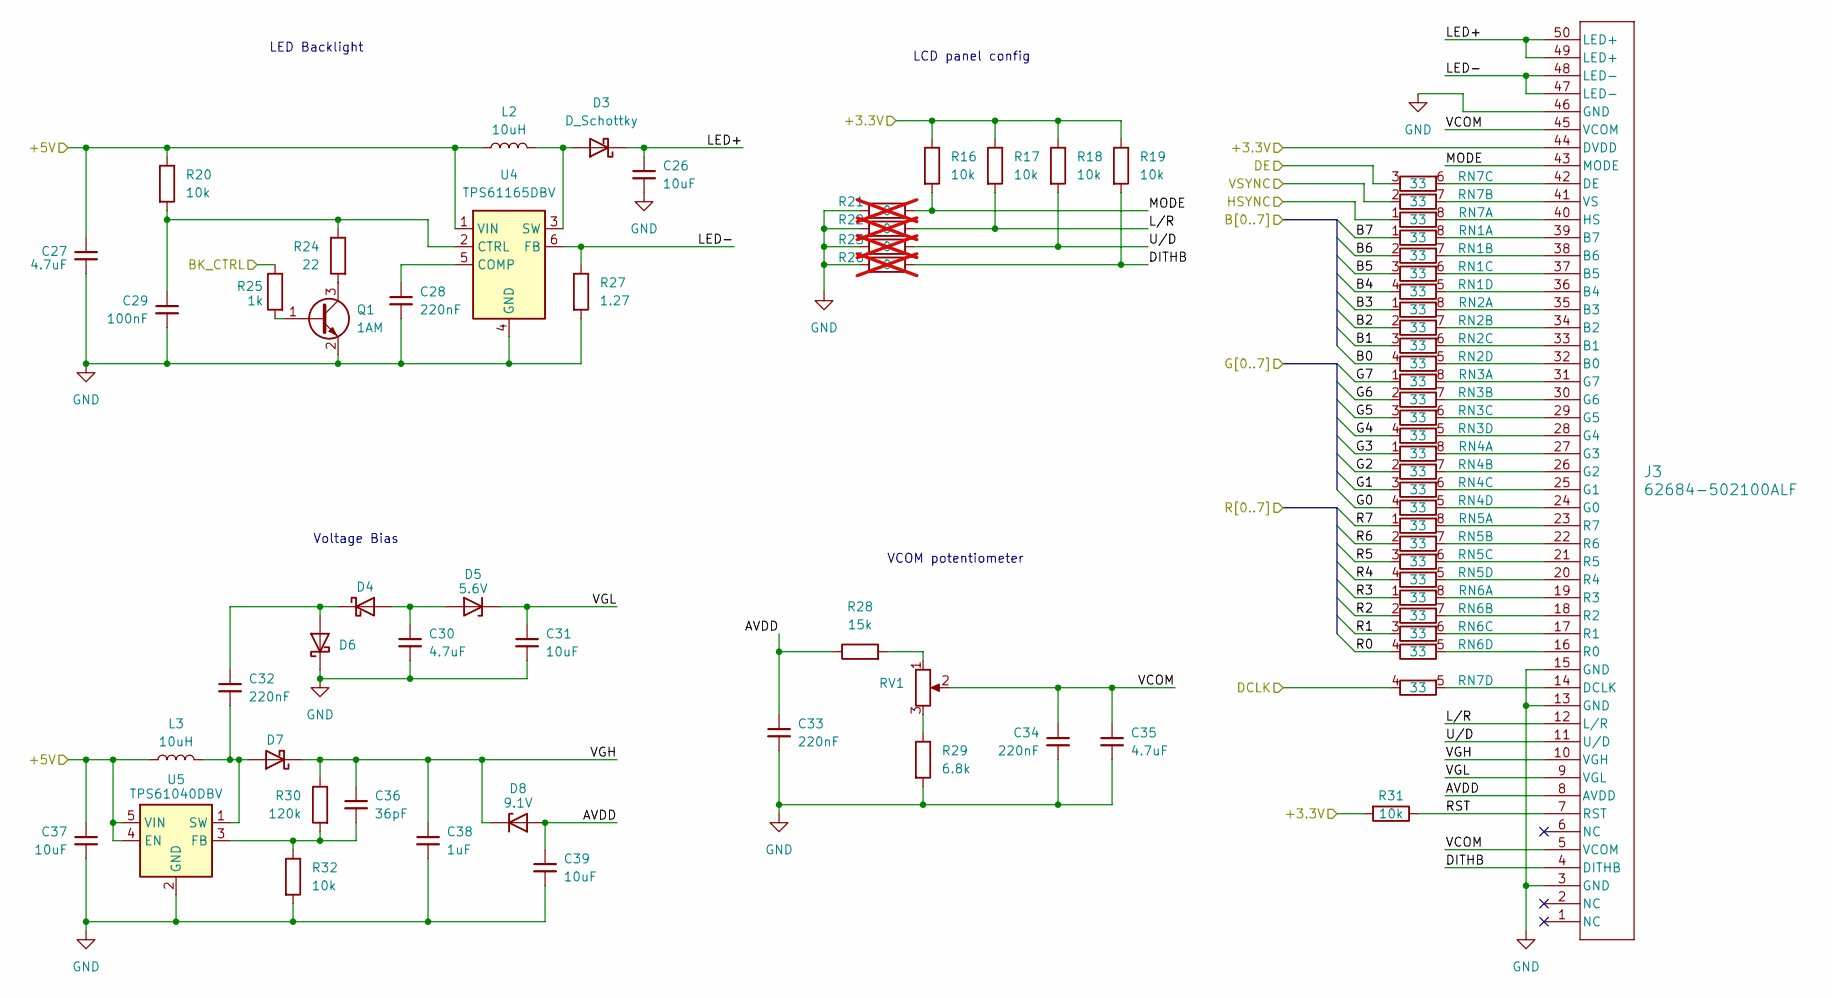
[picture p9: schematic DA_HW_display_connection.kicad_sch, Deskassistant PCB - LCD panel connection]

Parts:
C26, C31, C37, C39: 10uF; C_0805_2012Metric
C27, C30, C35: 4.7uF; C_0805_2012Metric
C28, C32, C33, C34: 220nF; C_0805_2012Metric
C29: 100nF; C_0805_2012Metric
C36: 36pF; C_0805_2012Metric
C38: 1uF; C_0805_2012Metric
D3, D4, D6, D7: D_Schottky; D_SMA
D5: 5.6V; D_SOD-123
D8: 9.1V; D_SOD-123
J3: 62684-502100ALF; CONN50_62684-502100ALF_FCI
L2, L3: 10uH; L_Sumida_CR75
Q1: 1AM; NXP_BC847A_215
R16, R17, R18, R19, R20, R31, R32: 10k; R_0805_2012Metric
R21, R22, R23, R26: 0; R_0805_2012Metric; not fitted
R24: 22; R_0805_2012Metric
R25: 1k; R_0805_2012Metric
R27: 1.27; R_0805_2012Metric
R28: 15k; R_0805_2012Metric
R29: 6.8k; R_0805_2012Metric
R30: 120k; R_0805_2012Metric
RN1, RN2, RN3, RN4, RN5, RN6, RN7: 33; R_Array_Convex_4x0603
RV1: Potentiometer_Bourns_3214J_Horizontal
U4: TPS61165DBV; SOT-23-6
U5: TPS61040DBV; SOT-23-5

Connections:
+5V: C27.1, C37.1, L2.1, L3.1, R20.1, U4.1 (VIN), U5.4 (EN), U5.5 (VIN); also elsewhere on the board
/+3.3V_DISP: J3.44 (DVDD), R16.1, R17.1, R18.1, R19.1, R31.2; also elsewhere on the board
/CM5/BK_CTRL: R25.1; also elsewhere on the board
/display connection/AVDD: C33.1, C39.1, D8.2 (A), J3.8 (AVDD), R28.1
/display connection/B0: RN2.4 (R4.1); also elsewhere on the board
/display connection/B1: RN2.3 (R3.1); also elsewhere on the board
/display connection/B2: RN2.2 (R2.1); also elsewhere on the board
/display connection/B3: RN2.1 (R1.1); also elsewhere on the board
/display connection/B4: RN1.4 (R4.1); also elsewhere on the board
/display connection/B5: RN1.3 (R3.1); also elsewhere on the board
/display connection/B6: RN1.2 (R2.1); also elsewhere on the board
/display connection/B7: RN1.1 (R1.1); also elsewhere on the board
/display connection/DCLK: RN7.4 (R4.1); also elsewhere on the board
/display connection/DE: RN7.3 (R3.1); also elsewhere on the board
/display connection/DITHB: J3.4 (DITHB), R19.2, R26.2
/display connection/G0: RN4.4 (R4.1); also elsewhere on the board
/display connection/G1: RN4.3 (R3.1); also elsewhere on the board
/display connection/G2: RN4.2 (R2.1); also elsewhere on the board
/display connection/G3: RN4.1 (R1.1); also elsewhere on the board
/display connection/G4: RN3.4 (R4.1); also elsewhere on the board
/display connection/G5: RN3.3 (R3.1); also elsewhere on the board
/display connection/G6: RN3.2 (R2.1); also elsewhere on the board
/display connection/G7: RN3.1 (R1.1); also elsewhere on the board
/display connection/HSYNC: RN7.1 (R1.1); also elsewhere on the board
/display connection/LED+: C26.1, D3.1 (K), J3.49 (LED+), J3.50 (LED+)
/display connection/LED-: J3.47 (LED-), J3.48 (LED-), R27.1, U4.6 (FB)
/display connection/L/R: J3.12 (L/R), R17.2, R22.2
/display connection/MODE: J3.43 (MODE), R16.2, R21.2
/display connection/R0: RN6.4 (R4.1); also elsewhere on the board
/display connection/R1: RN6.3 (R3.1); also elsewhere on the board
/display connection/R2: RN6.2 (R2.1); also elsewhere on the board
/display connection/R3: RN6.1 (R1.1); also elsewhere on the board
/display connection/R4: RN5.4 (R4.1); also elsewhere on the board
/display connection/R5: RN5.3 (R3.1); also elsewhere on the board
/display connection/R6: RN5.2 (R2.1); also elsewhere on the board
/display connection/R7: RN5.1 (R1.1); also elsewhere on the board
/display connection/RST: J3.7 (RST), R31.1
/display connection/U/D: J3.11 (U/D), R18.2, R23.2
/display connection/VCOM: C34.1, C35.1, J3.5 (VCOM), J3.45 (VCOM), RV1.2
/display connection/VGH: C36.1, C38.1, D7.1 (K), D8.1 (K), J3.10 (VGH), R30.1
/display connection/VGL: C31.1, D5.1 (K), J3.9 (VGL)
/display connection/VSYNC: RN7.2 (R2.1); also elsewhere on the board
GND: C26.2, C27.2, C28.2, C29.2, C30.2, C31.2, C33.2, C34.2, C35.2, C37.2, C38.2, C39.2, D6.1 (K), J3.3 (GND), J3.13 (GND), J3.15 (GND), J3.46 (GND), J3.51, Q1.2 (E), R21.1, R22.1, R23.1, R26.1, R27.2, R29.2, R32.2, U4.4 (GND), U5.2 (GND); also elsewhere on the board
unnamed: D3.2 (A), L2.2, U4.3 (SW)
unnamed: C30.1, D4.2 (A), D5.2 (A)
unnamed: C32.1, D4.1 (K), D6.2 (A)
unnamed: C32.2, D7.2 (A), L3.2, U5.1 (SW)
unnamed: J3.32 (B0), RN2.5 (R4.2)
unnamed: J3.33 (B1), RN2.6 (R3.2)
unnamed: J3.34 (B2), RN2.7 (R2.2)
unnamed: J3.35 (B3), RN2.8 (R1.2)
unnamed: J3.36 (B4), RN1.5 (R4.2)
unnamed: J3.37 (B5), RN1.6 (R3.2)
unnamed: J3.38 (B6), RN1.7 (R2.2)
unnamed: J3.39 (B7), RN1.8 (R1.2)
unnamed: J3.14 (DCLK), RN7.5 (R4.2)
unnamed: J3.42 (DE), RN7.6 (R3.2)
unnamed: J3.24 (G0), RN4.5 (R4.2)
unnamed: J3.25 (G1), RN4.6 (R3.2)
unnamed: J3.26 (G2), RN4.7 (R2.2)
unnamed: J3.27 (G3), RN4.8 (R1.2)
unnamed: J3.28 (G4), RN3.5 (R4.2)
unnamed: J3.29 (G5), RN3.6 (R3.2)
unnamed: J3.30 (G6), RN3.7 (R2.2)
unnamed: J3.31 (G7), RN3.8 (R1.2)
unnamed: J3.40 (HS), RN7.8 (R1.2)
unnamed: J3.16 (R0), RN6.5 (R4.2)
unnamed: J3.17 (R1), RN6.6 (R3.2)
unnamed: J3.18 (R2), RN6.7 (R2.2)
unnamed: J3.19 (R3), RN6.8 (R1.2)
unnamed: J3.20 (R4), RN5.5 (R4.2)
unnamed: J3.21 (R5), RN5.6 (R3.2)
unnamed: J3.22 (R6), RN5.7 (R2.2)
unnamed: J3.23 (R7), RN5.8 (R1.2)
unnamed: J3.41 (VS), RN7.7 (R2.2)
unnamed: Q1.1 (B), R25.2
unnamed: Q1.3 (C), R24.2
unnamed: R28.2, RV1.1
unnamed: R29.1, RV1.3
unnamed: C28.1, U4.5 (COMP)
unnamed: C29.1, R20.2, R24.1, U4.2 (CTRL)
unnamed: C36.2, R30.2, R32.1, U5.3 (FB)

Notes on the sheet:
VCOM potentiometer
LCD panel config
LED Backlight
Voltage Bias

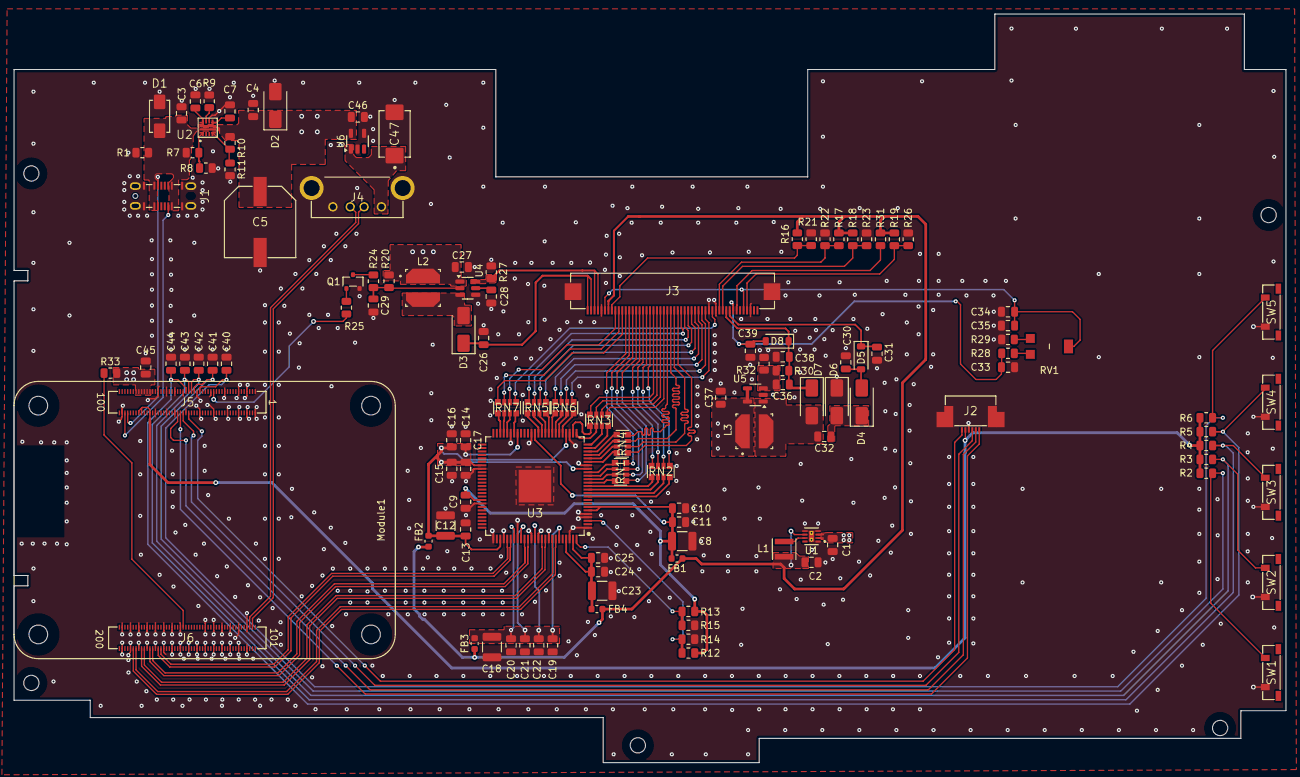
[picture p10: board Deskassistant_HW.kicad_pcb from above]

Board: 4 copper layers, 183.5 x 108.0 mm, 122 parts (0 on the bottom side), 119 nets.

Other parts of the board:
Module1: ComputeModule5-CM5; Raspberry-Pi-5-Compute-Module

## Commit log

2025-06-29 Initial public commit for HW data
    [Case - v1 v3.f3d, DA_HW_CM5.kicad_sch, DA_HW_display_connection.kicad_sch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]
2025-06-30 Update pcb schematic output pdf
    [Deskassistant_HW.kicad_pcb, Deskassistant_HW_BOM.ods]
2025-08-25 Fix HW rev B issues
    [DA_HW_CM5.kicad_sch, DA_HW_display_connection.kicad_sch, Deskassistant_HW.kicad_pcb]
2025-08-25 Add unit of measure to D8 value
    [DA_HW_display_connection.kicad_sch]
2025-09-01 Fix USB D+ and D- connections
    [DA_HW_CM5.kicad_sch, Deskassistant_HW.kicad_pcb]
